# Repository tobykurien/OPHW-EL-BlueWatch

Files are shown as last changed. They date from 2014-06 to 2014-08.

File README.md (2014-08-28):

House4Hack Watch
================

The House4Hack Watch, AKA BlueWatch, is a fork of the RetroWatch project. This is a "make your own smartwatch" with full schematics and instructions on flashing, as well as firmware and Android app.

Features:

- 128x64 OLED display
- Low cost (around $40)
- 3 buttons for navigation between watch apps
- Fully hackable - you can flash this firmware, your own firmware, or the RetroWatch firmware
- More to come...

References
==========

- RetroWatch Instructable: http://www.instructables.com/id/Make-your-own-smart-watch/
- OpenHardware Wiki: http://wiki.openhardware.co.za/index.php/House4Hack_BlueWatch_Project
- House4Hack discussion: https://groups.google.com/forum/#!topic/house4hack/jL63gTVElB0

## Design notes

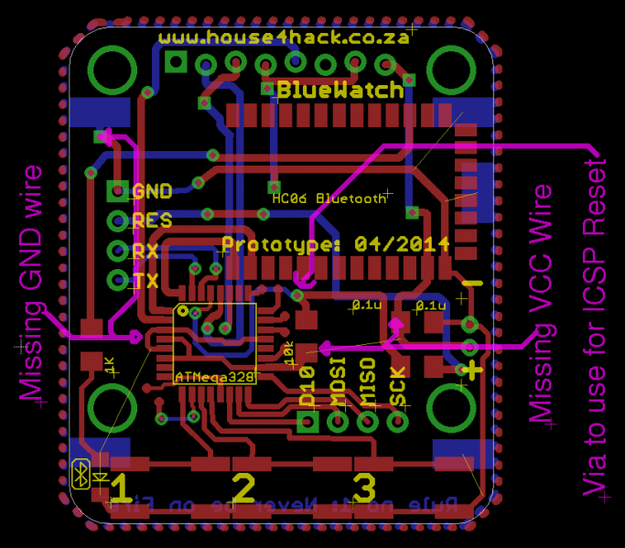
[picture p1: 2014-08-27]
docs/683px-Missing_Wires.png

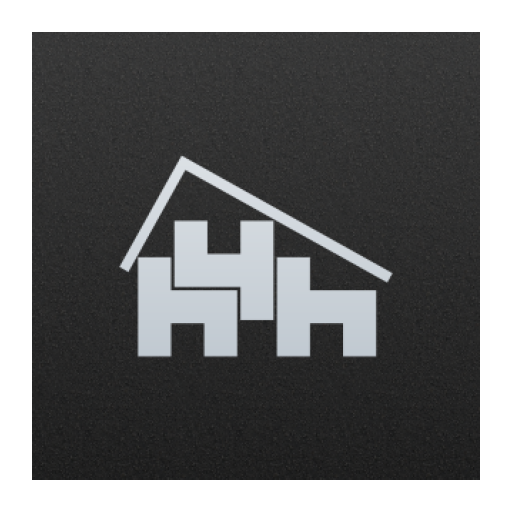
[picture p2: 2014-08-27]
h4h_watch/android/ic_launcher-web.png

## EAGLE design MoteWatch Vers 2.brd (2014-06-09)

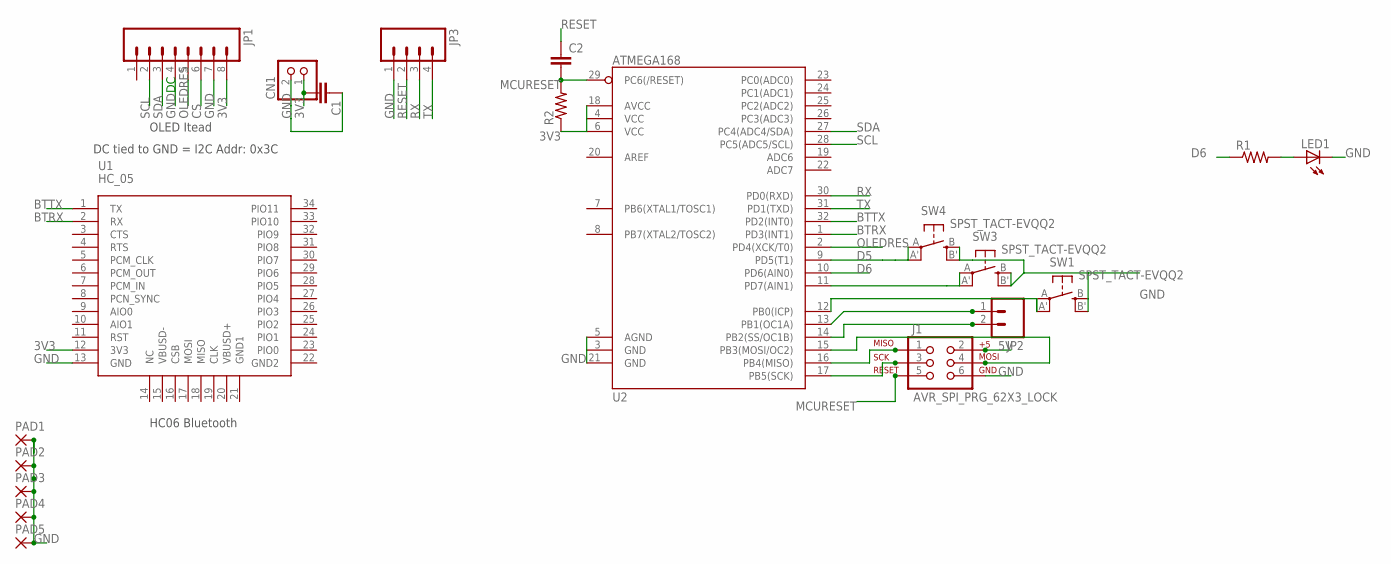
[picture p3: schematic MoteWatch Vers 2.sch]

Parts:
C1, C2: CAP1206; 1206
CN1: JST_2PIN-THM-RA; JST-PH-2-THM-RA
J1: AVR_SPI_PRG_62X3_LOCK; 2X3_LOCK
JP1: M08LOCK; 1X08_LOCK
JP2: M02LOCK; 1X02_LOCK
JP3: M04PTH; 1X04
LED1: LED1206; LED-1206
PAD1, PAD2, PAD3, PAD4, PAD5: SMD5; SMD2,54-5,08
R1, R2: RESISTOR1206; 1206
SW1, SW3, SW4: SPST_TACT-EVQQ2; EVQ-Q2
U1: HC_05; BLUETOOTH_SMD
U2: ATMEGA168; TQFP32-08

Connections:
3V3: C1.2, CN1.1 (2), JP1.8, R2.1, U1.12 (3V3), U2.4 (VCC), U2.6 (VCC), U2.18 (AVCC)
5V: J1.2
BTRX: U1.2 (RX), U2.1 (PD3(INT1))
BTTX: U1.1 (TX), U2.32 (PD2(INT0))
CS: JP1.6
D5: SW4.A, SW4.A' (P1), U2.9 (PD5(T1))
D6: R1.1, U2.10 (PD6(AIN0))
D7: SW3.A, SW3.A' (P1), U2.11 (PD7(AIN1))
D8: SW1.A, SW1.A' (P1), U2.12 (PB0(ICP))
D9: JP2.1, U2.13 (PB1(OC1A))
D10: JP2.2, U2.14 (PB2(SS/OC1B))
GND: C1.1, CN1.2 (1), J1.6, JP1.4, JP1.7, JP3.1, LED1.C, PAD1.1, PAD2.1, PAD3.1, PAD4.1, PAD5.1, SW1.B (S), SW1.B' (S1), SW3.B (S), SW3.B' (S1), SW4.B (S), SW4.B' (S1), U1.13 (GND), U2.3 (GND), U2.5 (AGND), U2.21 (GND)
MCURESET: C2.2, J1.5, R2.2, U2.29 (PC6(/RESET))
MISO: J1.1, U2.16 (PB4(MISO))
MOSI: J1.4, U2.15 (PB3(MOSI/OC2))
unnamed: LED1.A, R1.2
OLEDRES: JP1.5, U2.2 (PD4(XCK/T0))
RESET: C2.1, JP3.2
RX: JP3.3, U2.30 (PD0(RXD))
SCK: J1.3, U2.17 (PB5(SCK))
SCL: JP1.2, U2.28 (PC5(ADC5/SCL))
SDA: JP1.3, U2.27 (PC4(ADC4/SDA))
TX: JP3.4, U2.31 (PD1(TXD))

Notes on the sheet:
DC tied to GND = I2C Addr: 0x3C
OLED Itead
HC06 Bluetooth

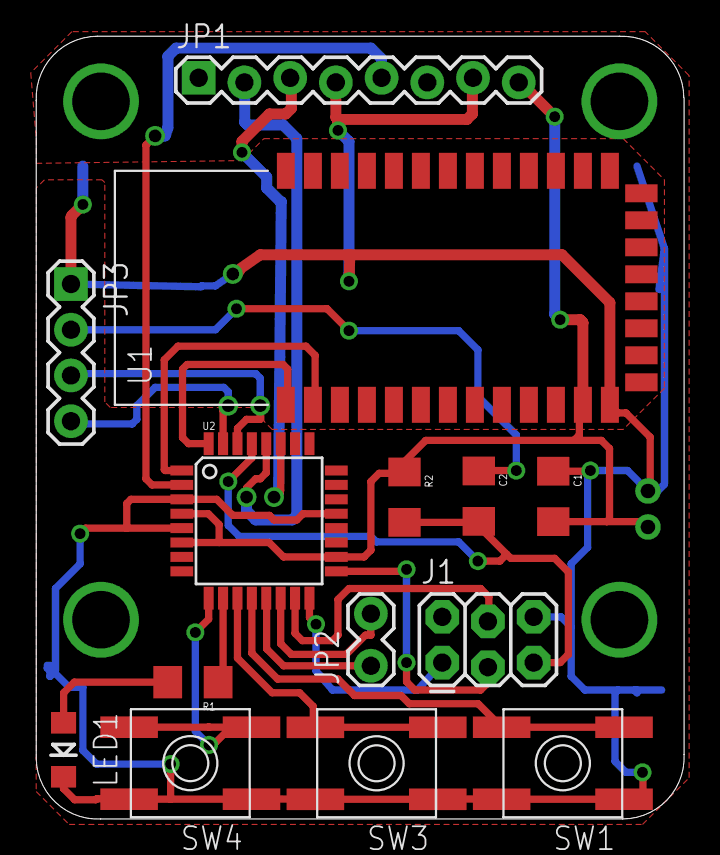
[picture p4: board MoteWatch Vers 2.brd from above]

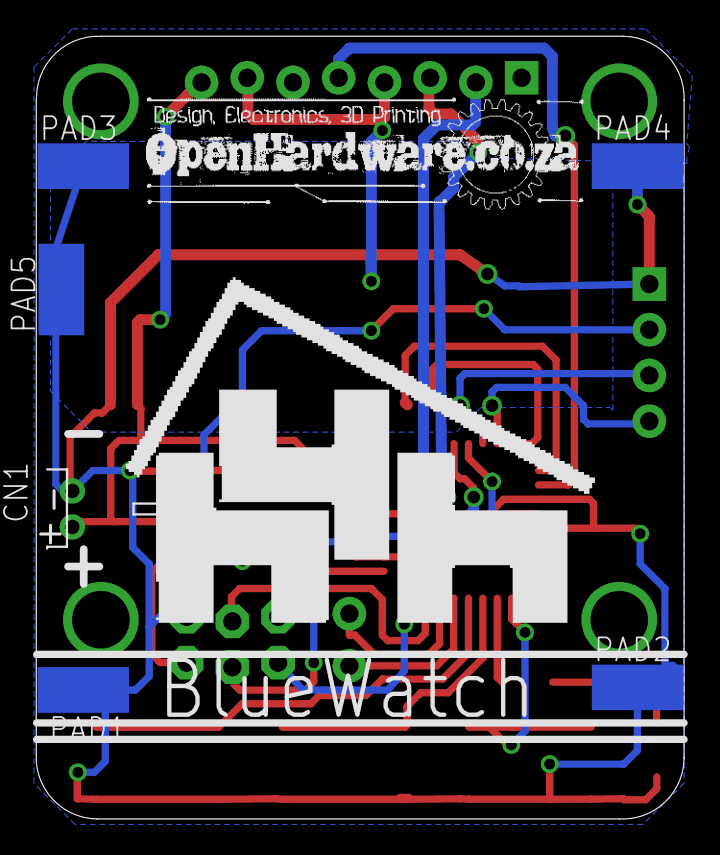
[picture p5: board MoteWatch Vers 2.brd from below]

Board: 2 copper layers, 36.0 x 43.5 mm, 20 parts (6 on the bottom side), 21 nets.

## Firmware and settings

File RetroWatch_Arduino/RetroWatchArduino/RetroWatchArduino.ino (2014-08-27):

/*
    RetroWatch Arduino is a part of open source smart watch project.
    Copyright (C) 2014  Suh Young Bae

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
    You should have received a copy of the GNU General Public License
    along with this program.  If not, see [http://www.gnu.org/licenses/].
*/
/*
Retro Watch Arduino v1.0

  Get the latest version, android host app at 
  ------> https://github.com/godstale/retrowatch
  ------> or http://www.hardcopyworld.com

Written by Suh Young Bae (godstale@hotmail.com)
All text above, and the first splash screen(Adafruit) must be included in any redistribution
*/

#include <avr/pgmspace.h>
#include <Wire.h>
#include <SPI.h>
#include <SoftwareSerial.h>
#include <Adafruit_GFX.h>
#include <Adafruit_SSD1306.h>
#include <math.h>
#include "bitmap.h"

///////////////////////////////////////////////////////////////////
int led = 6;


//----- OLED instance
#define OLED_RESET 4
Adafruit_SSD1306 display(OLED_RESET);

#if (SSD1306_LCDHEIGHT != 64)
#error("Height incorrect, please fix Adafruit_SSD1306.h!");
#endif
///////////////////////////////////////////////////////////////////

///////////////////////////////////////////////////////////////////
//----- BT instance
SoftwareSerial BTSerial(2, 3); //Connect HC-06, RX, TX
///////////////////////////////////////////////////////////////////

//----- Bluetooth transaction parsing
#define TR_MODE_IDLE 1
#define TR_MODE_WAIT_CMD 11
#define TR_MODE_WAIT_MESSAGE 101
#define TR_MODE_WAIT_TIME 111
#define TR_MODE_WAIT_ID 121
#define TR_MODE_WAIT_COMPLETE 201

#define TRANSACTION_START_BYTE 0xfc
#define TRANSACTION_END_BYTE 0xfd

#define CMD_TYPE_NONE 0x00
#define CMD_TYPE_RESET_EMERGENCY_OBJ 0x05
#define CMD_TYPE_RESET_NORMAL_OBJ 0x02
#define CMD_TYPE_RESET_USER_MESSAGE 0x03

#define CMD_TYPE_ADD_EMERGENCY_OBJ 0x11
#define CMD_TYPE_ADD_NORMAL_OBJ 0x12
#define CMD_TYPE_ADD_USER_MESSAGE 0x13

#define CMD_TYPE_DELETE_EMERGENCY_OBJ 0x21
#define CMD_TYPE_DELETE_NORMAL_OBJ 0x22
#define CMD_TYPE_DELETE_USER_MESSAGE 0x23

#define CMD_TYPE_SET_TIME 0x31
#define CMD_TYPE_REQUEST_MOVEMENT_HISTORY 0x32
#define CMD_TYPE_SET_CLOCK_STYLE 0x33
#define CMD_TYPE_SET_INDICATOR 0x34

#define CMD_TYPE_PING 0x51
#define CMD_TYPE_AWAKE 0x52
#define CMD_TYPE_SLEEP 0x53
#define CMD_TYPE_REBOOT 0x54

byte TRANSACTION_POINTER = TR_MODE_IDLE;
byte TR_COMMAND = CMD_TYPE_NONE;

//----- Message item buffer
#define MSG_COUNT_MAX 7
#define MSG_BUFFER_MAX 19
unsigned char msgBuffer[MSG_COUNT_MAX][MSG_BUFFER_MAX];
char msgParsingLine = 0;
char msgParsingChar = 0;
char msgCurDisp = 0;

//----- Emergency item buffer
#define EMG_COUNT_MAX 3
#define EMG_BUFFER_MAX 19
char emgBuffer[EMG_COUNT_MAX][EMG_BUFFER_MAX];
char emgParsingLine = 0;
char emgParsingChar = 0;
char emgCurDisp = 0;

//----- Time
#define UPDATE_TIME_INTERVAL 60000
byte iMonth = 1;
byte iDay = 1;
byte iWeek = 1;    // 1: SUN, MON, TUE, WED, THU, FRI,SAT
byte iAmPm = 0;    // 0:AM, 1:PM
byte iHour = 0;
byte iMinutes = 0;
byte iSecond = 0;

#define TIME_BUFFER_MAX 6
char timeParsingIndex = 0;
char timeBuffer[6] = {-1, -1, -1, -1, -1, -1};
PROGMEM const char* weekString[] = {"", "Sun", "Mon", "Tue", "Wed", "Thu", "Fri", "Sat"};
PROGMEM const char* ampmString[] = {"AM", "PM"};

//----- Display features
#define DISPLAY_MODE_START_UP 0
#define DISPLAY_MODE_CLOCK 1
#define DISPLAY_MODE_EMERGENCY_MSG 2
#define DISPLAY_MODE_NORMAL_MSG 3
#define DISPLAY_MODE_IDLE 11
byte displayMode = DISPLAY_MODE_START_UP;

#define CLOCK_STYLE_SIMPLE_ANALOG  0x01
#define CLOCK_STYLE_SIMPLE_DIGIT  0x02
#define CLOCK_STYLE_SIMPLE_MIX  0x03
byte clockStyle = CLOCK_STYLE_SIMPLE_MIX;

#define INDICATOR_ENABLE 0x01
boolean updateIndicator = true;

byte centerX = 64;
byte centerY = 32;
byte iRadius = 28;

#define IDLE_DISP_INTERVAL 60000
#define CLOCK_DISP_INTERVAL 60000
#define EMERGENCY_DISP_INTERVAL 5000
#define MESSAGE_DISP_INTERVAL 3000
unsigned long prevClockTime = 0;
unsigned long prevDisplayTime = 0;

unsigned long next_display_interval = 0;
unsigned long mode_change_timer = 0;
#define CLOCK_DISPLAY_TIME 300000
#define EMER_DISPLAY_TIME 10000
#define MSG_DISPLAY_TIME 5000

//----- Button control
int buttonPin = 5;
boolean isClicked = false;



void setup()   {
  //Serial.begin(9600);    // Do not enable serial. This makes serious problem because of shortage of RAM.
  pinMode(buttonPin, INPUT_PULLUP);  // Defines button pin
   pinMode(led, OUTPUT);  
   delay(200); 
  digitalWrite(led, HIGH);
  delay(200); 
  digitalWrite(led, LOW);
  delay(200); 

  init_emg_array();
  init_msg_array();
  
  //----- by default, we'll generate the high voltage from the 3.3v line internally! (neat!)
  display.begin(SSD1306_SWITCHCAPVCC, 0x3c);  // initialize with the I2C addr 0x3D (for the 128x64)
  digitalWrite(led, HIGH);
  delay(200); 
  digitalWrite(led, LOW);
  delay(200); 
  display.display();    // show splashscreen
  digitalWrite(led, HIGH);
  delay(200); 
  digitalWrite(led, LOW);
  delay(200); 
  digitalWrite(led, HIGH);
  delay(200); 
  digitalWrite(led, LOW);
  delay(200); 
  drawStartUp();    // Show RetroWatch Logo
   centerX = display.width() / 2;
  centerY = display.height() / 2;
  iRadius = centerY - 2;

  BTSerial.begin(9600);  // set the data rate for the BT port
  digitalWrite(led, LOW);

}


void loop() {
  digitalWrite(led, !digitalRead(led));
  boolean isReceived = false;
  unsigned long current_time = 0;
  
  // Get button input
  if(digitalRead(buttonPin) == LOW) isClicked = true;
  
  // Receive data from remote and parse
  isReceived = receiveBluetoothData();
  
  // Update clock time
  current_time = millis();
  updateTime(current_time);
  
  // Display routine
  onDraw(current_time);
  
  // If data doesn't arrive, wait for a while to save battery
  if(!isReceived)
    delay(300);
}




///////////////////////////////////
//----- Utils
///////////////////////////////////
void init_msg_array() {
  for(int i=0; i<MSG_COUNT_MAX; i++) {
    for(int j=0; j<MSG_BUFFER_MAX; j++) {
      msgBuffer[i][j] = 0x00;
    }
  }
  msgParsingLine = 0;
  msgParsingChar = 0;    // First 2 byte is management byte
  msgCurDisp = 0;
}

void init_emg_array() {
  for(int i=0; i<EMG_COUNT_MAX; i++) {
    for(int j=0; j<EMG_BUFFER_MAX; j++) {
      emgBuffer[i][j] = 0x00;
    }
  }
  emgParsingLine = 0;
  emgParsingChar = 0;    // First 2 byte is management byte
  emgCurDisp = 0;
}

///////////////////////////////////
//----- Time functions
///////////////////////////////////
void setTimeValue() {
  iMonth = timeBuffer[0];
  iDay = timeBuffer[1];
  iWeek = timeBuffer[2];    // 1: SUN, MON, TUE, WED, THU, FRI,SAT
  iAmPm = timeBuffer[3];    // 0:AM, 1:PM
  iHour = timeBuffer[4];
  iMinutes = timeBuffer[5];
}

void updateTime(unsigned long current_time) {
  if(iMinutes >= 0) {
    if(current_time - prevClockTime > UPDATE_TIME_INTERVAL) {
      // Increase time
      iMinutes++;
      if(iMinutes >= 60) {
        iMinutes = 0;
        iHour++;
        if(iHour > 12) {
          iHour = 1;
          (iAmPm == 0) ? iAmPm=1 : iAmPm=0;
          if(iAmPm == 0) {
            iWeek++;
            if(iWeek > 7)
              iWeek = 1;
            iDay++;
            if(iDay > 30)  // Yes. day is not exact.
              iDay = 1;
          }
        }
      }
      prevClockTime = current_time;
    }
  }
  else {
    displayMode = DISPLAY_MODE_START_UP;
  }
}

///////////////////////////////////
//----- BT, Data parsing functions
///////////////////////////////////

// Parsing packet according to current mode
boolean receiveBluetoothData() {
  int isTransactionEnded = false;
  while(!isTransactionEnded) {
    if(BTSerial.available()) {
      byte c = BTSerial.read();
      
      if(c == 0xFF && TRANSACTION_POINTER != TR_MODE_WAIT_MESSAGE) return false;
      
      if(TRANSACTION_POINTER == TR_MODE_IDLE) {
        parseStartSignal(c);
      }
      else if(TRANSACTION_POINTER == TR_MODE_WAIT_CMD) {
        parseCommand(c);
      }
      else if(TRANSACTION_POINTER == TR_MODE_WAIT_MESSAGE) {
        parseMessage(c);
      }
      else if(TRANSACTION_POINTER == TR_MODE_WAIT_TIME) {
        parseTime(c);
      }
      else if(TRANSACTION_POINTER == TR_MODE_WAIT_ID) {
        parseId(c);
      }
      else if(TRANSACTION_POINTER == TR_MODE_WAIT_COMPLETE) {
        isTransactionEnded = parseEndSignal(c);
      }
      
    }  // End of if(BTSerial.available())
    else {
      isTransactionEnded = true;
    }
  }  // End of while()
  return true;
}  // End of receiveBluetoothData()

void parseStartSignal(byte c) {
  //drawLogChar(c);
  if(c == TRANSACTION_START_BYTE) {
    TRANSACTION_POINTER = TR_MODE_WAIT_CMD;
    TR_COMMAND = CMD_TYPE_NONE;
  }
}

void parseCommand(byte c) {
  if(c == CMD_TYPE_RESET_EMERGENCY_OBJ || c == CMD_TYPE_RESET_NORMAL_OBJ || c == CMD_TYPE_RESET_USER_MESSAGE) {
    TRANSACTION_POINTER = TR_MODE_WAIT_COMPLETE;
    TR_COMMAND = c;
    processTransaction();
  }
  else if(c == CMD_TYPE_ADD_EMERGENCY_OBJ || c == CMD_TYPE_ADD_NORMAL_OBJ || c == CMD_TYPE_ADD_USER_MESSAGE) {
    TRANSACTION_POINTER = TR_MODE_WAIT_MESSAGE;
    TR_COMMAND = c;
    if(c == CMD_TYPE_ADD_EMERGENCY_OBJ) {
      emgParsingChar = 0;
      if(emgParsingLine >= MSG_COUNT_MAX || emgParsingLine < 0)
        emgParsingLine = 0;
    }
    else if(c == CMD_TYPE_ADD_NORMAL_OBJ) {
      msgParsingChar = 0;
      if(msgParsingLine >= MSG_COUNT_MAX || msgParsingLine < 0)
        msgParsingLine = 0;
    }
  }
  else if(c == CMD_TYPE_DELETE_EMERGENCY_OBJ || c == CMD_TYPE_DELETE_NORMAL_OBJ || c == CMD_TYPE_DELETE_USER_MESSAGE) {
    TRANSACTION_POINTER = TR_MODE_WAIT_COMPLETE;
    TR_COMMAND = c;
  }
  else if(c == CMD_TYPE_SET_TIME) {
    TRANSACTION_POINTER = TR_MODE_WAIT_TIME;
    TR_COMMAND = c;
  }
  else if(c == CMD_TYPE_SET_CLOCK_STYLE || c == CMD_TYPE_SET_INDICATOR) {
    TRANSACTION_POINTER = TR_MODE_WAIT_ID;
    TR_COMMAND = c;
  }
  else {
    TRANSACTION_POINTER = TR_MODE_IDLE;
    TR_COMMAND = CMD_TYPE_NONE;
  }
}

void parseMessage(byte c) {
  if(c == TRANSACTION_END_BYTE) {
    processTransaction();
    TRANSACTION_POINTER = TR_MODE_IDLE;
  }
  
  if(TR_COMMAND == CMD_TYPE_ADD_EMERGENCY_OBJ) {
    if(emgParsingChar < EMG_BUFFER_MAX) {
      if(emgParsingChar > 1) {
        emgBuffer[emgParsingLine][emgParsingChar] = c;
      }
      emgParsingChar++;
    }
    else {
      TRANSACTION_POINTER = TR_MODE_WAIT_COMPLETE;
    }
  }
  else if(TR_COMMAND == CMD_TYPE_ADD_NORMAL_OBJ) {
    if(msgParsingChar < MSG_BUFFER_MAX) {
      if(msgParsingChar > 1) {
        msgBuffer[msgParsingLine][msgParsingChar] = c;
      }
      msgParsingChar++;
    }
    else {
      TRANSACTION_POINTER = TR_MODE_WAIT_COMPLETE;
    }
  }
  else if(TR_COMMAND == CMD_TYPE_ADD_USER_MESSAGE) {
    // Not available yet.
    TRANSACTION_POINTER = TR_MODE_WAIT_COMPLETE;
  }
}

void parseTime(byte c) {
  if(TR_COMMAND == CMD_TYPE_SET_TIME) {
    if(timeParsingIndex >= 0 && timeParsingIndex < TIME_BUFFER_MAX) {
      timeBuffer[timeParsingIndex] = (int)c;
      timeParsingIndex++;
    }
    else {
      processTransaction();
      TRANSACTION_POINTER = TR_MODE_WAIT_COMPLETE;
    }
  }
}

void parseId(byte c) {
  if(TR_COMMAND == CMD_TYPE_SET_CLOCK_STYLE) {
    clockStyle = c;
    processTransaction();
  }
  else if(TR_COMMAND == CMD_TYPE_SET_INDICATOR) {
    if(c == INDICATOR_ENABLE)
      updateIndicator = true;
    else
      updateIndicator = false;
    processTransaction();
  }
  TRANSACTION_POINTER = TR_MODE_WAIT_COMPLETE;
}

boolean parseEndSignal(byte c) {
  if(c == TRANSACTION_END_BYTE) {
    TRANSACTION_POINTER = TR_MODE_IDLE;
    return true;
  }
  return false;
}

void processTransaction() {
  if(TR_COMMAND == CMD_TYPE_RESET_EMERGENCY_OBJ) {
    init_emg_array();//init_msg_array();
  }
  else if(TR_COMMAND == CMD_TYPE_RESET_NORMAL_OBJ) {
    init_msg_array();//init_emg_array();
  }
  else if(TR_COMMAND == CMD_TYPE_RESET_USER_MESSAGE) {
    // Not available yet.
  }
  else if(TR_COMMAND == CMD_TYPE_ADD_NORMAL_OBJ) {
    msgBuffer[msgParsingLine][0] = 0x01;
    msgParsingChar = 0;
    msgParsingLine++;
    if(msgParsingLine >= MSG_COUNT_MAX)
      msgParsingLine = 0;
    setNextDisplayTime(millis(), 0);  // update screen immediately
  }
  else if(TR_COMMAND == CMD_TYPE_ADD_EMERGENCY_OBJ) {
    emgBuffer[emgParsingLine][0] = 0x01;
    emgParsingChar = 0;
    emgParsingLine++;
    if(emgParsingLine >= EMG_COUNT_MAX)
      emgParsingLine = 0;
    startEmergencyMode();
    setNextDisplayTime(millis(), 2000);
  }
  else if(TR_COMMAND == CMD_TYPE_ADD_USER_MESSAGE) {
  }
  else if(TR_COMMAND == CMD_TYPE_DELETE_EMERGENCY_OBJ || TR_COMMAND == CMD_TYPE_DELETE_NORMAL_OBJ || TR_COMMAND == CMD_TYPE_DELETE_USER_MESSAGE) {
    // Not available yet.
  }
  else if(TR_COMMAND == CMD_TYPE_SET_TIME) {
    setTimeValue();
    timeParsingIndex = 0;
    setNextDisplayTime(millis(), 0);  // update screen immediately
  }
  if(TR_COMMAND == CMD_TYPE_SET_CLOCK_STYLE || CMD_TYPE_SET_INDICATOR) {
    setNextDisplayTime(millis(), 0);  // update screen immediately
  }
}

///////////////////////////////////
//----- Drawing methods
///////////////////////////////////

// Main drawing routine.
// Every drawing starts here.
void onDraw(unsigned long currentTime) {
  if(!isDisplayTime(currentTime))    // Do not re-draw at every tick
    return;
  
  if(displayMode == DISPLAY_MODE_START_UP) {
    drawStartUp();
  }
  else if(displayMode == DISPLAY_MODE_CLOCK) {
    if(isClicked == LOW) {    // User input received
      startEmergencyMode();
      setPageChangeTime(0);    // Change mode with no page-delay
      setNextDisplayTime(currentTime, 0);    // Do not wait next re-draw time
    }
    else {
      drawClock();
      
      if(isPageChangeTime(currentTime)) {  // It's time to go into idle mode
        startIdleMode();
        setPageChangeTime(currentTime);  // Set a short delay
      }
      setNextDisplayTime(currentTime, CLOCK_DISP_INTERVAL);
    }
  }
  else if(displayMode == DISPLAY_MODE_EMERGENCY_MSG) {
    if(findNextEmerMessage()) {
      drawEmergency();
      emgCurDisp++;
      if(emgCurDisp >= EMG_COUNT_MAX) {
        emgCurDisp = 0;
        startMessageMode();
      }
      setNextDisplayTime(currentTime, EMERGENCY_DISP_INTERVAL);
    }
    // There's no message left to display. Go to normal message mode.
    else {
      startMessageMode();
      //setPageChangeTime(0);
      setNextDisplayTime(currentTime, 0);  // with no re-draw interval
    }
  }
  else if(displayMode == DISPLAY_MODE_NORMAL_MSG) {
    if(findNextNormalMessage()) {
      drawMessage();
      msgCurDisp++;
      if(msgCurDisp >= MSG_COUNT_MAX) {
        msgCurDisp = 0;
        startClockMode();
      }
      setNextDisplayTime(currentTime, MESSAGE_DISP_INTERVAL);
    }
    // There's no message left to display. Go to clock mode.
    else {
      startClockMode();
      setPageChangeTime(currentTime);
      setNextDisplayTime(currentTime, 0);  // with no re-draw interval
    }
  }
  else if(displayMode == DISPLAY_MODE_IDLE) {
    if(isClicked == LOW) {    // Wake up watch if there's an user input
      startClockMode();
      setPageChangeTime(currentTime);
      setNextDisplayTime(currentTime, 0);
    } 
    else {
      drawIdleClock();
      setNextDisplayTime(currentTime, IDLE_DISP_INTERVAL);
    }
  }
  else {
    startClockMode();    // This means there's an error
  }
  
  isClicked = HIGH;
}  // End of onDraw()


// To avoid re-draw on every drawing time
// wait for time interval according to current mode 
// But user input(button) breaks this sleep
boolean isDisplayTime(unsigned long currentTime) {
  if(currentTime - prevDisplayTime > next_display_interval) {
    return true;
  }
  if(isClicked == LOW) {
    delay(500);
    return true;
  }
  return false;
}

// Set next re-draw time 
void setNextDisplayTime(unsigned long currentTime, unsigned long nextUpdateTime) {
  next_display_interval = nextUpdateTime;
  prevDisplayTime = currentTime;
}

// Decide if it's the time to change page(mode)
boolean isPageChangeTime(unsigned long currentTime) {
  if(displayMode == DISPLAY_MODE_CLOCK) {
    if(currentTime - mode_change_timer > CLOCK_DISPLAY_TIME)
      return true;
  }
  return false;
}

// Set time interval to next page(mode)
void setPageChangeTime(unsigned long currentTime) {
  mode_change_timer = currentTime;
}

// Check if available emergency message exists or not
boolean findNextEmerMessage() {
  if(emgCurDisp < 0 || emgCurDisp >= EMG_COUNT_MAX) emgCurDisp = 0;
  while(true) {
    if(emgBuffer[emgCurDisp][0] == 0x00) {  // 0x00 means disabled
      emgCurDisp++;
      if(emgCurDisp >= EMG_COUNT_MAX) {
        emgCurDisp = 0;
        return false;
      }
    }
    else {
      break;
    }
  }  // End of while()
  return true;
}

// Check if available normal message exists or not
boolean findNextNormalMessage() {
  if(msgCurDisp < 0 || msgCurDisp >= MSG_COUNT_MAX) msgCurDisp = 0;
  while(true) {
    if(msgBuffer[msgCurDisp][0] == 0x00) {
      msgCurDisp++;
      if(msgCurDisp >= MSG_COUNT_MAX) {
        msgCurDisp = 0;
        return false;
      }
    }
    else {
      break;
    }
  }  // End of while()
  return true;
}

// Count all available emergency messages
int countEmergency() {
  int count = 0;
  for(int i=0; i<EMG_COUNT_MAX; i++) {
    if(emgBuffer[i][0] != 0x00)
      count++;
  }
  return count;
}

// Count all available normal messages
int countMessage() {
  int count = 0;
  for(int i=0; i<MSG_COUNT_MAX; i++) {
    if(msgBuffer[i][0] != 0x00)
      count++;
  }
  return count;
}

void startClockMode() {
  displayMode = DISPLAY_MODE_CLOCK;
}

void startEmergencyMode() {
  displayMode = DISPLAY_MODE_EMERGENCY_MSG;
  emgCurDisp = 0;
}

void startMessageMode() {
  displayMode = DISPLAY_MODE_NORMAL_MSG;
  msgCurDisp = 0;
}

void startIdleMode() {
  displayMode = DISPLAY_MODE_IDLE;
}

// Draw indicator. Indicator shows count of emergency and normal message
void drawIndicator() {
  if(updateIndicator) {
    int msgCount = countMessage();
    int emgCount = countEmergency();
    int drawCount = 1;
    
    if(msgCount > 0) {
      display.drawBitmap(127 - 8, 1, IMG_indicator_msg, 8, 8, WHITE);
      display.setTextColor(WHITE);
      display.setTextSize(1);
      display.setCursor(127 - 15, 1);
      display.print(msgCount);
      drawCount++;
    }
    
    if(emgCount > 0) {
      display.drawBitmap(127 - 8*drawCount - 7*(drawCount-1), 1, IMG_indicator_emg, 8, 8, WHITE);
      display.setTextColor(WHITE);
      display.setTextSize(1);
      display.setCursor(127 - 8*drawCount - 7*drawCount, 1);
      display.print(emgCount);
    }

  }
}

// RetroWatch splash screen
void drawStartUp() {
  display.clearDisplay();
  
  display.drawBitmap(10, 15, IMG_logo_24x24, 24, 24, WHITE);
  
  display.setTextSize(2);
  display.setTextColor(WHITE);
  display.setCursor(45,12);
  display.println("Retro");
  display.setCursor(45,28);
  display.println("Watch");
  display.setTextSize(1);
  display.setCursor(45,45);
  display.setTextColor(WHITE);
  display.println("Arduino v1.0");
  display.display();
  delay(2000);
  
  startClockMode();
}

// Draw emergency message page
void drawEmergency() {
  int icon_num = 60;
  display.clearDisplay();
  
  if(updateIndicator)
    drawIndicator();
  
  if(emgBuffer[emgCurDisp][2] > -1 && emgBuffer[emgCurDisp][2] < ICON_ARRAY_SIZE)
    icon_num = (int)(emgBuffer[emgCurDisp][2]);
  
  drawIcon(centerX - 8, centerY - 20, icon_num);
  
  display.setTextColor(WHITE);
  display.setTextSize(1);
  display.setCursor(getCenterAlignedXOfEmg(emgCurDisp), centerY + 10);
  for(int i=3; i<EMG_BUFFER_MAX; i++) {
    char curChar = emgBuffer[emgCurDisp][i];
    if(curChar == 0x00) break;
    if(curChar >= 0xf0) continue;
    display.write(curChar);
  }

  display.display();
}

// Draw normal message page
void drawMessage() {
  int icon_num = 0;
  display.clearDisplay();
  
  if(updateIndicator)
    drawIndicator();
  
  if(msgBuffer[msgCurDisp][2] > -1 && msgBuffer[msgCurDisp][2] < ICON_ARRAY_SIZE)
    icon_num = (int)(msgBuffer[msgCurDisp][2]);
  
  drawIcon(centerX - 8, centerY - 20, icon_num);
  
  display.setTextColor(WHITE);
  display.setTextSize(1);
  display.setCursor(getCenterAlignedXOfMsg(msgCurDisp), centerY + 10);
//  display.print(msgCurDisp);  // For debug
  for(int i=3; i<MSG_BUFFER_MAX; i++) {
    char curChar = msgBuffer[msgCurDisp][i];
    if(curChar == 0x00) break;
    if(curChar >= 0xf0) continue;
    display.write(curChar);
  }

  display.display();
}
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

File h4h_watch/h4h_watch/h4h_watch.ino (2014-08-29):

#include <Wire.h>
#include <MultiLCD.h>
#include <SoftwareSerial.h>

//----- OLED instance
LCD_SSD1306 lcd; /* for SSD1306 OLED module */

//----- BT instance
SoftwareSerial BTSerial(2, 3); //Connect HC-06, RX, TX

//----- Hardware buttons
int BUTTON1 = 5;
int button1State = HIGH;

int BUTTON2 = 7;
int button2State = HIGH;

int BUTTON3 = 8;
int button3State = HIGH;

//----- Hardware LED
int LED1 = 6;

//----- Bluetooth commands
const byte CMD_FRAME_BUFFER = 0x1;

const byte STATE_IDLE = 0x1;
const byte STATE_READING = 0x2;

byte state = STATE_IDLE;
int stateFbCounter = 0; // counter for reading frame buffer data
long lastBtRead = 0;
const int BT_TIMEOUT_SECS = 10;

//----- Display frame buffer
const int FRAME_BUFFER_SIZE = SSD1306_LCDWIDTH * SSD1306_LCDHEIGHT / 8;
static byte frame_buf[FRAME_BUFFER_SIZE];

const int DISPLAY_TIMEOUT_SECS = 10;
long display_timeout = millis();
boolean display_awake = true;

void setup() {
  lcd.begin();
  
  pinMode(BUTTON1, INPUT_PULLUP);
  pinMode(BUTTON2, INPUT_PULLUP);
  pinMode(BUTTON3, INPUT_PULLUP);
  pinMode(LED1, OUTPUT);
  
  BTSerial.begin(9600); // set the data rate for the BT port
  Serial.begin(9600); 

  // clear frame buffer
  for (int i=0; i < FRAME_BUFFER_SIZE; i++) {
    frame_buf[i] = 0x0;
  }
  
  drawWelcome();
  requestFrameBuffer();
}

void loop() {
  handleButtons();
  handleBluetooth();
  handleDisplayTimeout();
  delay(10); // power saving
}

void handleButtons() {
  boolean transition = false;
  
  if (digitalRead(BUTTON1) == LOW && button1State == HIGH) {
    // transition
    button1State = LOW;
    transition = true;
    digitalWrite(LED1, HIGH);
  }

  if (digitalRead(BUTTON1) == HIGH && button1State == LOW) {
    // transition
    button1State = HIGH;
    transition = true;
    digitalWrite(LED1, LOW);
    sendButton(1);
  }

  if (digitalRead(BUTTON2) == LOW && button2State == HIGH) {
    // transition
    transition = true;
    button2State = LOW;
  }

  if (digitalRead(BUTTON2) == HIGH && button2State == LOW) {
    // transition
    transition = true;
    button2State = HIGH;
    sendButton(2);
  }

  if (digitalRead(BUTTON3) == LOW && button3State == HIGH) {
    // transition
    transition = true;
    button3State = LOW;
  }

  if (digitalRead(BUTTON3) == HIGH && button3State == LOW) {
    // transition
    transition = true;
    button3State = HIGH;
    sendButton(3);
  }

  if (transition) {
    if (button1State == LOW || button2State == LOW || button3State == LOW) {
      lcd.invertDisplay(1);      
      if (!display_awake) requestFrameBuffer();
    } else {
      lcd.invertDisplay(0);
    }
  }
}

void handleBluetooth() {
  if (millis()/1000 - lastBtRead > BT_TIMEOUT_SECS) {
    state = STATE_IDLE;
    stateFbCounter = 0;
  }
  
  while (BTSerial.available()) {
    byte c = BTSerial.read();
    if (state == STATE_IDLE && c == CMD_FRAME_BUFFER) {
      // start reading frame buffer data
      state = STATE_READING;
      stateFbCounter = 0;
    } else if (state == STATE_READING) {
      frame_buf[stateFbCounter++] = c;
      if (stateFbCounter >= FRAME_BUFFER_SIZE) {
        // done reading frame buffer
        state = STATE_IDLE;
        wakeDisplay();
        drawFrameBuffer();
      }
    }
  }
}

void sendButton(int button) {
  if (state == STATE_IDLE && display_awake) {
    if (button == 1) BTSerial.write("BUTTON1\n");
    else if (button == 2) BTSerial.write("BUTTON2\n");
    else if (button == 3) BTSerial.write("BUTTON3\n");
  }
}

void requestFrameBuffer() {
  lastBtRead = millis()/1000;
  
  // send a request to the watch for a frame buffer to display
  BTSerial.write("FRAME_BUFFER\n");
}

void handleDisplayTimeout() {
  if (display_awake == true && (millis()/1000 - display_timeout) > DISPLAY_TIMEOUT_SECS) {
    lcd.clear();
    display_awake = false;
  }
}

void wakeDisplay() {
  display_timeout = millis() / 1000;
  display_awake = true;
}

void drawWelcome() {
  lcd.clear();

  lcd.setCursor(0, 0);
  lcd.setFont(FONT_SIZE_SMALL);
  lcd.print("House4Hack Watch");
  lcd.setCursor(0, 1);
  lcd.print("v0.01-alpha");
  lcd.setCursor(0, 2);
  lcd.print("");
  lcd.setCursor(0, 3);
  lcd.print("Load app and");
  lcd.setCursor(0, 4);
  lcd.print("connect to start");
}

void drawFrameBuffer() {
/*
  for (int page=0; page < 16; page++)
    for (int x=0; x < 128; x++)
      lcd.draw8x8(&frame_buf[0], x*(page+1), page);
*/
    lcd.ssd1306_command(SSD1306_SETLOWCOLUMN | 0x0);  // low col = 0
    lcd.ssd1306_command(SSD1306_SETHIGHCOLUMN | 0x0);  // hi col = 0
    lcd.ssd1306_command(SSD1306_SETSTARTLINE | 0x0); // line #0

    // save I2C bitrate
    uint8_t twbrbackup = TWBR;
    TWBR = 18; // upgrade to 400KHz!

    byte *p = frame_buf;
    byte x = 0;
    byte y = 0;
    byte width = 128;
    byte height = 64;

    height >>= 3;
    width >>= 3;
    y >>= 3;
    for (byte i = 0; i < height; i++) {
      // send a bunch of data in one xmission
        lcd.ssd1306_command(0xB0 + i + y);//set page address
        lcd.ssd1306_command(x & 0xf);//set lower column address
        lcd.ssd1306_command(0x10 | (x >> 4));//set higher column address

        for(byte j = 0; j < 8; j++){
            Wire.beginTransmission(SSD1306_I2C_ADDRESS);
            Wire.write(0x40);
            for (byte k = 0; k < width; k++, p++) {
                Wire.write(*p);
            }
            Wire.endTransmission();
        }
    }
    TWBR = twbrbackup;  
}

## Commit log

2014-06-09 Revision for second order
    [MoteWatch Vers 2.GBL, MoteWatch Vers 2.GBO, MoteWatch Vers 2.GBP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]
2014-06-16 Firmware as tested
    Firmware as installed on Rev 2 prototypes delivered to H4H this week
2014-08-26 fixed button by enabling internal pullup on pin 5
    [RetroWatchArduino.ino]
2014-08-27 implemented sending frame buffer from app to watch
2014-08-27 added button presses to watch state
2014-08-28 fixed display timeout, refactored code to run as a service rather than from activity. First usable watch functionality.
    [h4h_watch.ino]
2014-08-28 fixed display timeout issues, added watch status to notification
    [h4h_watch.ino]
2014-08-28 fixed off-by-one error in frame buffer converter
    [h4h_watch.ino]
2014-08-29 added bluetooth timeout when waiting for frame buffer
2014-08-29 added House4Hack Entry module, added support for module switching with middle button, and primary/secondary action with other buttons
2014-08-29 fixed buttons being sent on wakeup, changed to always wake up to the clock
    [h4h_watch.ino]
2014-09-03 support for more than one module when switching modules/clock

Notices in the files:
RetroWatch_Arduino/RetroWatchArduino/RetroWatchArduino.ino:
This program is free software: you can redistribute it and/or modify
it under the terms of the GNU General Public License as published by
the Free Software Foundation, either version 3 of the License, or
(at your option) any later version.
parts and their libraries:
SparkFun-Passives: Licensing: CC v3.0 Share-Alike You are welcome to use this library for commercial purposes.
